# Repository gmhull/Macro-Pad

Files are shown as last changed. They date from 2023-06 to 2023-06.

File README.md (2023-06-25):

# Macro-Pad
This project was inspired by the ocreeb-12 project <a href='https://github.com/sb-ocr/ocreeb-12'>here</a>.  A big part of this project for me was ordering my first custom PCB.  All my other projects so far have been soldered breadboards.  It took some time to learn, but this process makes the final circuit so much easier to work with.

PCB files were created using EagleCad.  I used Solidworks to create the STL models for printing.  

BOM for the project:
<ul>
  <li>KB2040 board - 1
  <li>1N4148W Diode - 12
  <li>Cherry MX Mechanical Keys - 12
  <li>MX Key Caps - 12
  <li>Neopixel 5050 LEDs - 4
  <li>Custom PCB - 1
  <li>Encoder - 2
  <li>Rubber Feet - 4
  <li>10 kOhm Resistor - 1
  <li>0.1 uF capacitor - 4
</ul>

STL files can be found on my printables page, <a href=''>here</a>.

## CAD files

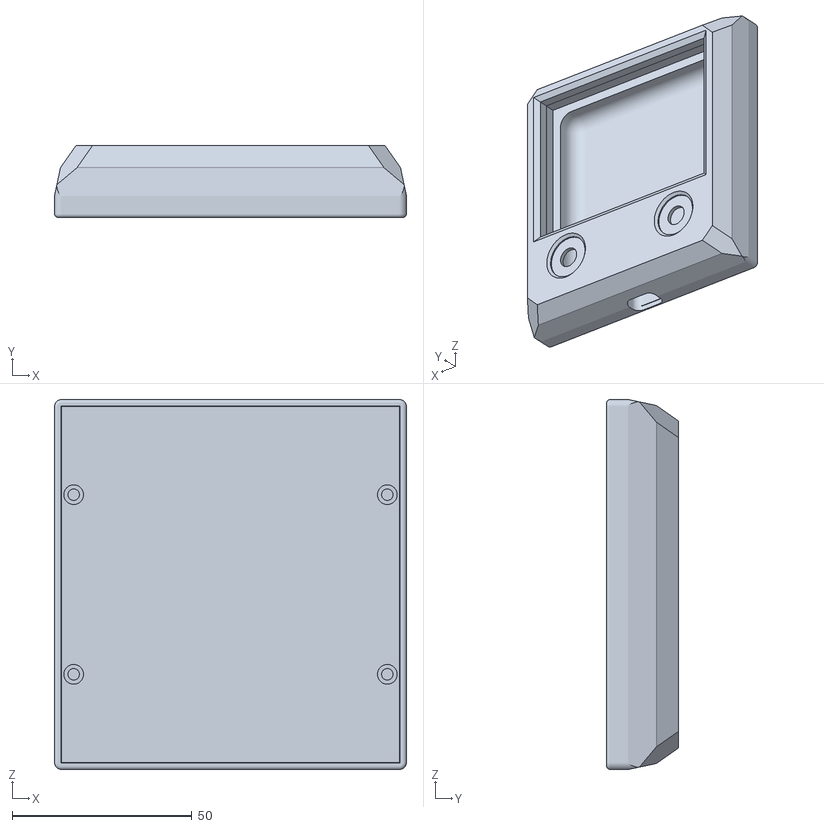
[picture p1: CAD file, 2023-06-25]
STL Files/Macropad Case.STL
98.0 x 20.0 x 103.0

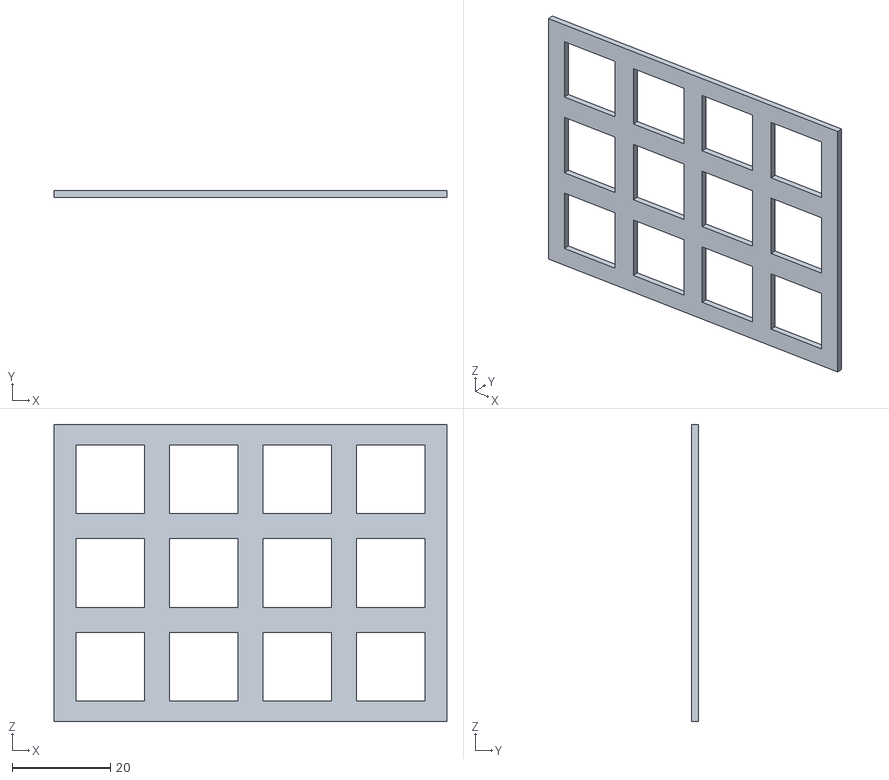
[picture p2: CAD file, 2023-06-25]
STL Files/Cherry MX Keys Guide.STL
80.0 x 1.41 x 60.5

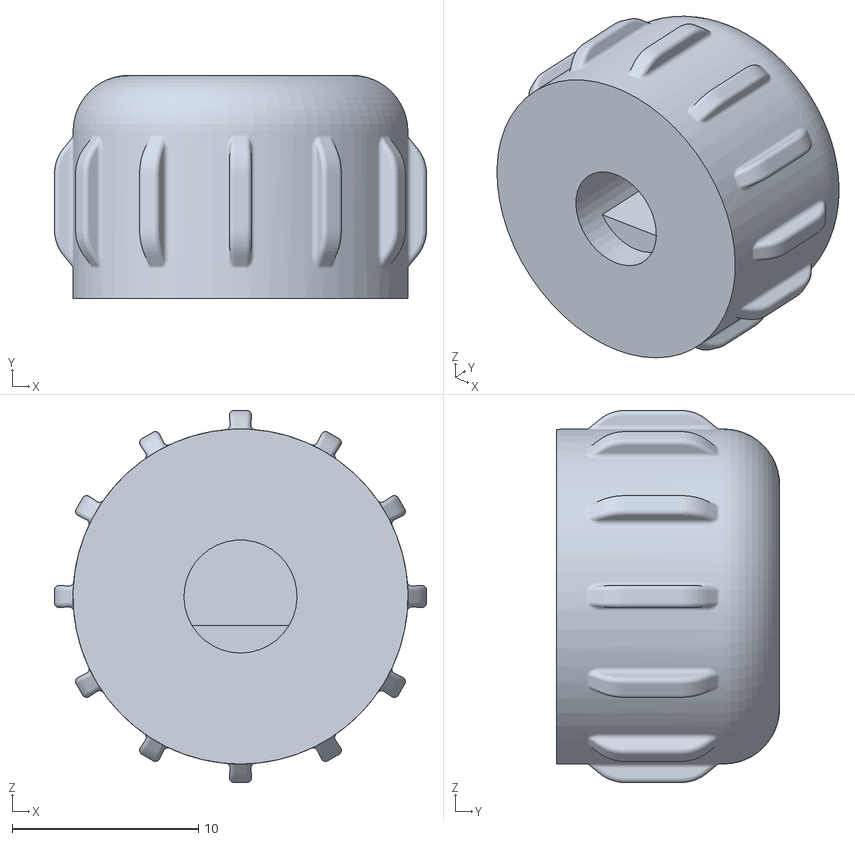
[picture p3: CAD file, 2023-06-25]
STL Files/Macropad Knob.STL
20.0 x 12.0 x 20.0

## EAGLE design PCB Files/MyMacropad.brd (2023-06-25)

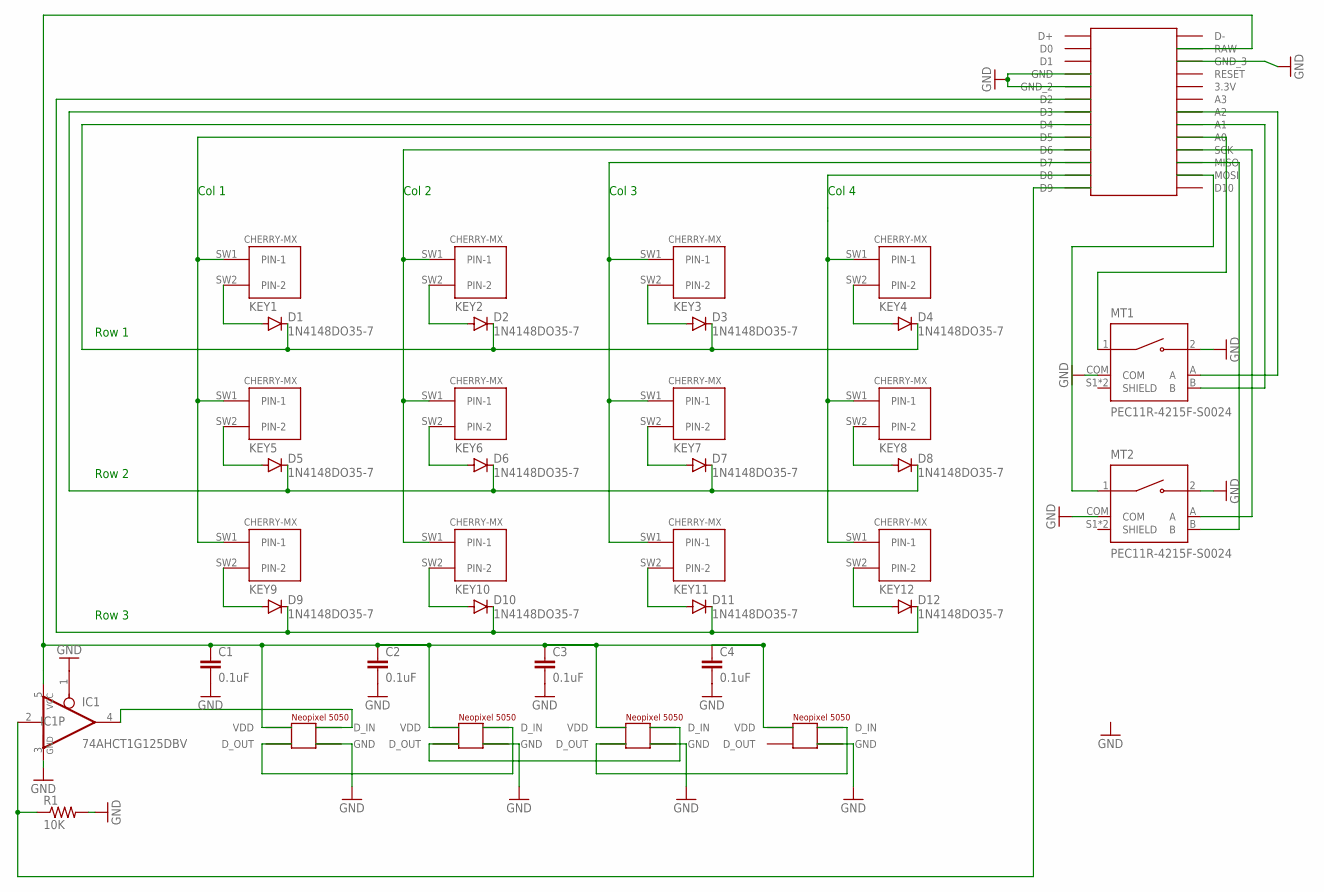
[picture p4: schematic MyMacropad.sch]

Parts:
C1, C2, C3, C4: 0.1uF; CAP-PTH-SMALL-KIT
D1, D2, D3, D4, D5, D6, D7, D8, D9, D10, D11, D12: 1N4148DO35-7; DO35-7
IC1: 74AHCT1G125DBV; SOT23-5
KEY1, KEY2, KEY3, KEY4, KEY5, KEY6, KEY7, KEY8, KEY9, KEY10, KEY11, KEY12: CHERRY-MX
MT1, MT2: PEC11R-4215F-S0024; XDCR_PEC11R-4215F-S0024
NEOPIXEL_1, NEOPIXEL_2, NEOPIXEL_3, NEOPIXEL_4: NEOPIXEL_5050
R1: 10K; V234/12
U$5: KB2040

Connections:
GND: C1.2, C2.2, C3.2, C4.2, IC1.1 (OE), IC1.3 (GND), MT1.2, MT1.COM, MT2.2, MT2.COM, NEOPIXEL_1.GND, NEOPIXEL_2.GND, NEOPIXEL_3.GND, NEOPIXEL_4.GND, R1.2, U$5.GND, U$5.GND_2, U$5.GND_3
unnamed: KEY1.SW1 (PIN-1), KEY5.SW1 (PIN-1), KEY9.SW1 (PIN-1), U$5.D5
unnamed: KEY2.SW1 (PIN-1), KEY6.SW1 (PIN-1), KEY10.SW1 (PIN-1), U$5.D6
unnamed: KEY3.SW1 (PIN-1), KEY7.SW1 (PIN-1), KEY11.SW1 (PIN-1), U$5.D7
unnamed: D1.A, KEY1.SW2 (PIN-2)
unnamed: KEY4.SW1 (PIN-1), KEY8.SW1 (PIN-1), KEY12.SW1 (PIN-1), U$5.D8
unnamed: D2.A, KEY2.SW2 (PIN-2)
unnamed: D6.A, KEY6.SW2 (PIN-2)
unnamed: D10.A, KEY10.SW2 (PIN-2)
unnamed: D9.A, KEY9.SW2 (PIN-2)
unnamed: D7.A, KEY7.SW2 (PIN-2)
unnamed: D11.A, KEY11.SW2 (PIN-2)
unnamed: D3.A, KEY3.SW2 (PIN-2)
unnamed: D4.A, KEY4.SW2 (PIN-2)
unnamed: D8.A, KEY8.SW2 (PIN-2)
unnamed: D12.A, KEY12.SW2 (PIN-2)
unnamed: D1.C, D2.C, D3.C, D4.C, U$5.D4
unnamed: IC1.4 (O), NEOPIXEL_1.D_IN
unnamed: NEOPIXEL_3.D_OUT, NEOPIXEL_4.D_IN
unnamed: D5.A, KEY5.SW2 (PIN-2)
unnamed: NEOPIXEL_1.D_OUT, NEOPIXEL_2.D_IN
unnamed: D5.C, D6.C, D7.C, D8.C, U$5.D3
unnamed: D9.C, D10.C, D11.C, D12.C, U$5.D2
unnamed: NEOPIXEL_2.D_OUT, NEOPIXEL_3.D_IN
unnamed: IC1.2 (I), R1.1, U$5.D9
unnamed: C1.1, C2.1, C3.1, C4.1, IC1.5 (VCC), NEOPIXEL_1.VDD, NEOPIXEL_2.VDD, NEOPIXEL_3.VDD, NEOPIXEL_4.VDD, U$5.RAW
unnamed: MT1.A, U$5.A2
unnamed: MT1.B, U$5.A1
unnamed: MT1.1, U$5.A0
unnamed: MT2.1, U$5.MOSI
unnamed: MT2.A, U$5.SCK
unnamed: MT2.B, U$5.MISO

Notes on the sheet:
Col 1
Col 2
Col 3
Col 4
Row 1
Row 2
Row 3

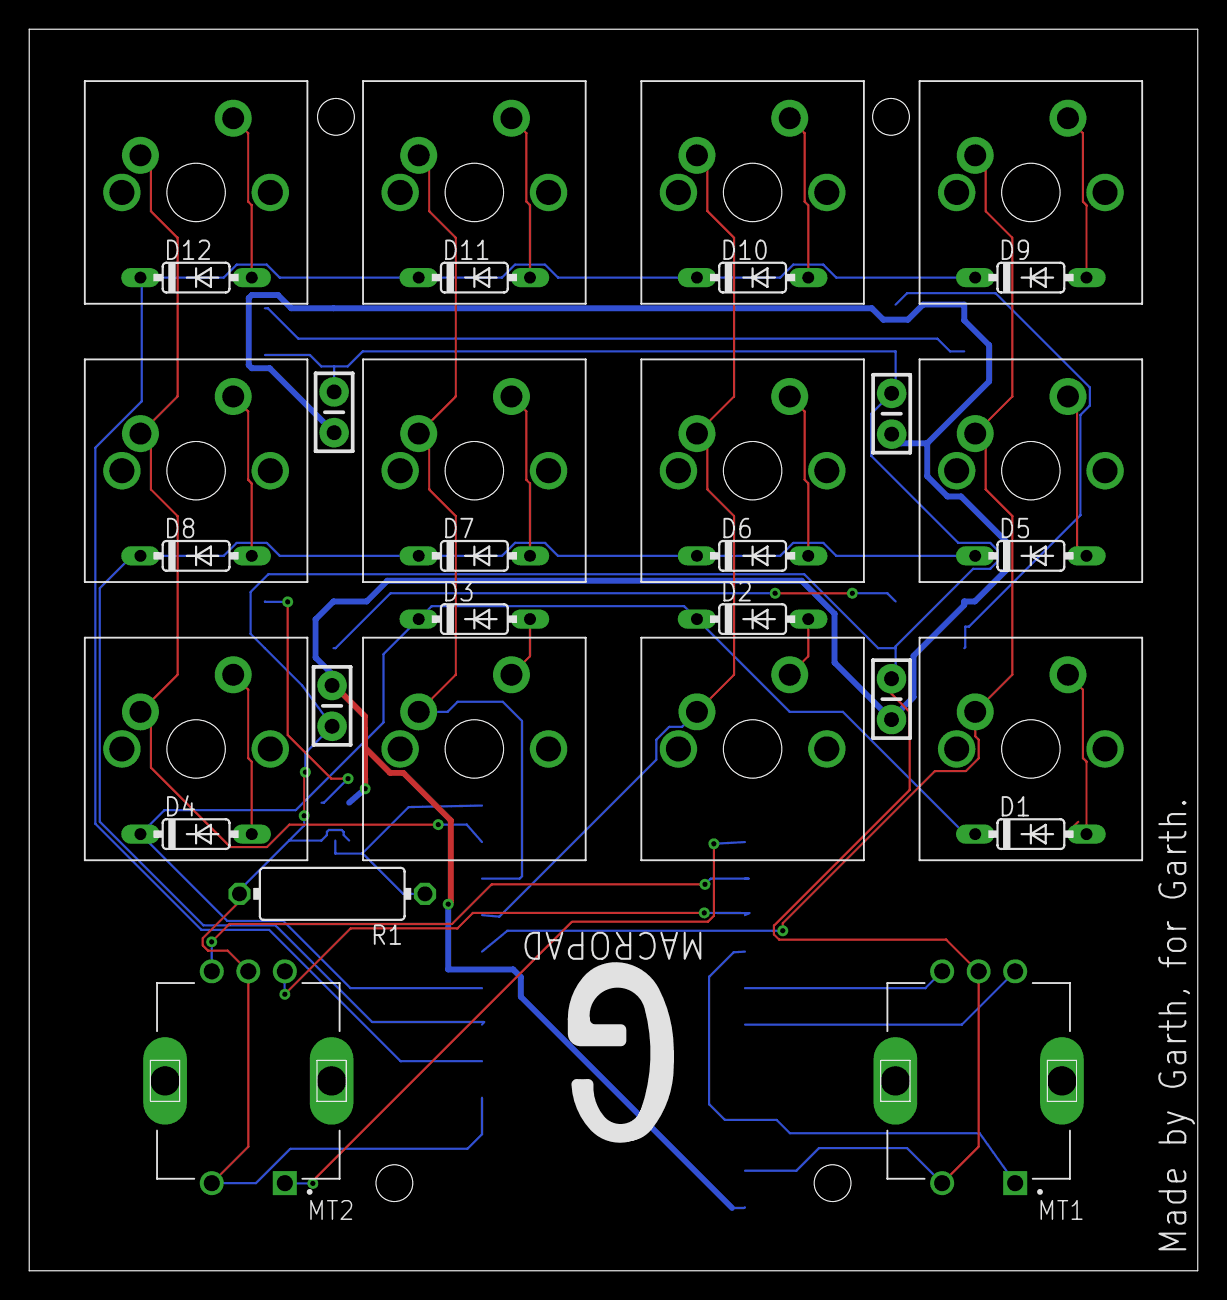
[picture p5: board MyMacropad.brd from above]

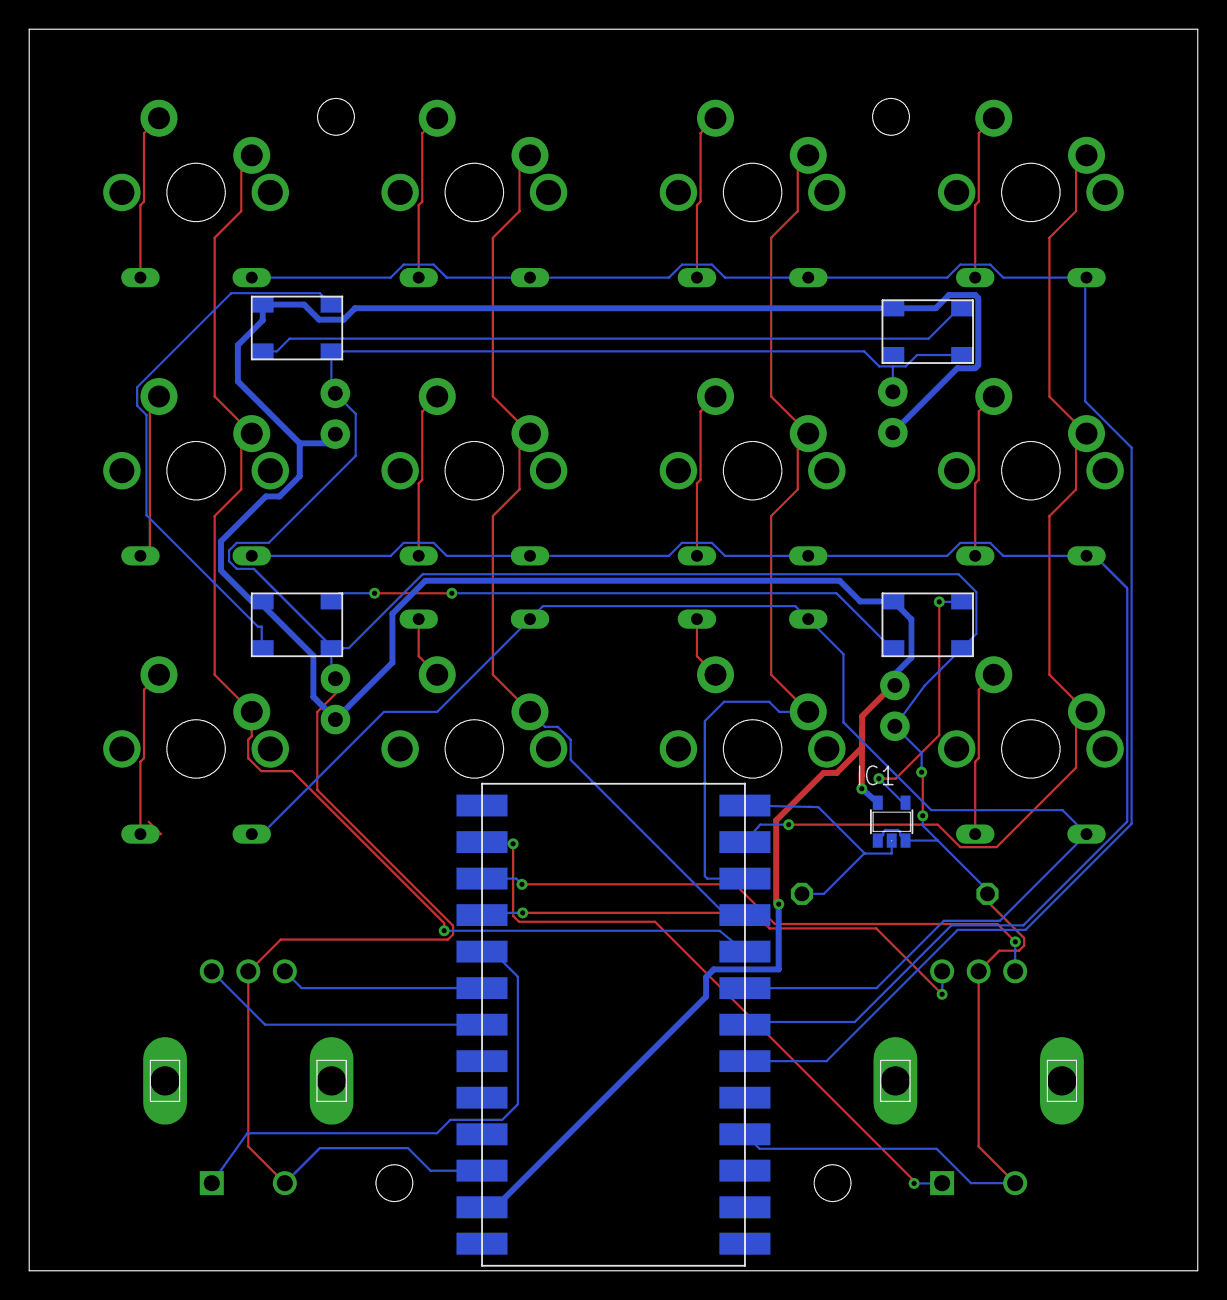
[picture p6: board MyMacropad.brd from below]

Board: 2 copper layers, 80.0 x 85.0 mm, 37 parts (6 on the bottom side), 32 nets.

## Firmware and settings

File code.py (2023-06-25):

print("Starting")

import board

from kmk.kmk_keyboard import KMKKeyboard
from kmk.keys import KC
from kmk.scanners import DiodeOrientation
from kmk.modules.encoder import EncoderHandler
from kmk.modules.layers import Layers
from kmk.extensions.rgb import RGB
from kmk.extensions.media_keys import MediaKeys
from kmk.handlers.sequences import send_string, simple_key_sequence

# Set-Up
layers = Layers()
keyboard = KMKKeyboard()
encoder_handler = EncoderHandler()
keyboard.modules = [layers, encoder_handler]

rgb = RGB(pixel_pin=board.D9, 
          num_pixels=4,
          hue_default=165,
          )
keyboard.extensions.append(rgb)
keyboard.extensions.append(MediaKeys())

keyboard.col_pins = (board.D5,board.D6,board.D7,board.D8)
keyboard.row_pins = (board.D4,board.D3,board.D2)
encoder_handler.pins = (
    # Left Encoder
    (board.D1, board.D10, board.D0,),
    # Right Encoder
    (board.SCK, board.MISO, board.MOSI,),
)
keyboard.diode_orientation = DiodeOrientation.COL2ROW

FN = KC.MO(1)
TOG_RGB_LAYER = KC.TG(2)
_______ = KC.TRNS
XXXXXXX = KC.NO

# Macro Functions
def open_file(file_name):
    command = simple_key_sequence([KC.LWIN(KC.S), KC.MACRO_SLEEP_MS(200), send_string(file_name), KC.ENTER])
    return command

def open_instructions():
    # Open a notepad
    open_file("Notepad")
    # Read instructions file
    f = open("instructions.txt", "r")
    # Write the contents of the instructions file into the notepad
    send_string(f.read())
    send_string("Howdy")
    
def open_link(link):
    simple_key_sequence([KC.LWIN(KC.R), KC.MACRO_SLEEP_MS(200), send_string(link), KC.ENTER])

# Macros
# Universal Shortcuts
OPEN_EXCEL = simple_key_sequence([KC.LWIN(KC.LCTRL(KC.LSFT(KC.LALT(KC.X))))])
COPY = simple_key_sequence([KC.LCTRL(KC.C)])
CUT = simple_key_sequence([KC.LCTRL(KC.X)])
PASTE_AS_VALUES = simple_key_sequence([KC.LCTRL(KC.LALT(KC.V)), KC.MACRO_SLEEP_MS(200), KC.V, KC.MACRO_SLEEP_MS(200), KC.ENTER])
UNDO = simple_key_sequence([KC.LCTRL(KC.Z)])
REDO = simple_key_sequence([KC.LCTRL(KC.Y)])

# Programs
# Manually add a key shortcut to any desktop shortcut by right clicking and going to the properties menu.
SOLIDWORKS = open_file('Solidworks')
INSTRUCTIONS = open_instructions()

# Links
RICK_ROLL = open_link('https://www.youtube.com/watch?v=dQw4w9WgXcQ')
GARTHS_WORLD = open_link('https://www.Garths.World')

# Keymaps
keyboard.keymap = [
    # Base Layer
    [
        KC.A, XXXXXXX, OPEN_EXCEL, COPY,
        INSTRUCTIONS, XXXXXXX, XXXXXXX, CUT,
        FN, UNDO, REDO, PASTE_AS_VALUES,
     ],
    # Function Layer
    [
        RICK_ROLL, SOLIDWORKS, XXXXXXX, XXXXXXX,
        GARTHS_WORLD, XXXXXXX, XXXXXXX, XXXXXXX,
        XXXXXXX, XXXXXXX, XXXXXXX, XXXXXXX,
     ],
    # RGB Layer
    [
        XXXXXXX, XXXXXXX, XXXXXXX, XXXXXXX,
        XXXXXXX, KC.RGB_MODE_SWIRL, KC.RGB_MODE_KNIGHT, KC.RGB_MODE_RAINBOW,
        TOG_RGB_LAYER, KC.RGB_MODE_PLAIN, KC.RGB_MODE_BREATHE, KC.RGB_MODE_BREATHE_RAINBOW
     ],
]
encoder_handler.map = [
    (( KC.VOLD, KC.VOLU, KC.MUTE), ( KC.RGB_VAD, KC.RGB_VAI, KC.RGB_TOG)),
    (( KC.VOLD, KC.VOLU, KC.MUTE), ( KC.RGB_HUD, KC.RGB_HUI, TOG_RGB_LAYER)),
    (( KC.VOLD, KC.VOLU, KC.MUTE), ( KC.RGB_HUD, KC.RGB_HUI, TOG_RGB_LAYER)),
]

if __name__ == '__main__':
    keyboard.go()
    

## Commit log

2023-06-25 Added PCD Files
    [MyMacropad.brd, MyMacropad.sch]
2023-06-25 Added STL Files
    [Cherry MX Keys Guide.STL, Macropad Case.STL, Macropad Knob.STL]

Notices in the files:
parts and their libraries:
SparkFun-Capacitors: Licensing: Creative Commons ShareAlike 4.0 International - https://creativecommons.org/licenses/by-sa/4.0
